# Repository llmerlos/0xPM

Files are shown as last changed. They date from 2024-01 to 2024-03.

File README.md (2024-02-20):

# PICCTRL - 0xPM
## 3x6 + 4 Split Ortholinear Keyboard with on board MCU

## Characteristics:
* [FAK](https://github.com/semickolon/fak) powered
* CH552
* ESD, over-current, short-circuit, reverse polarity protection.
* [Acrylic case](https://github.com/llmerlos/OxPM/PCB/svgs).
* Reversible PCB
* MX and Choc V1 compatibility.

### Choc V1
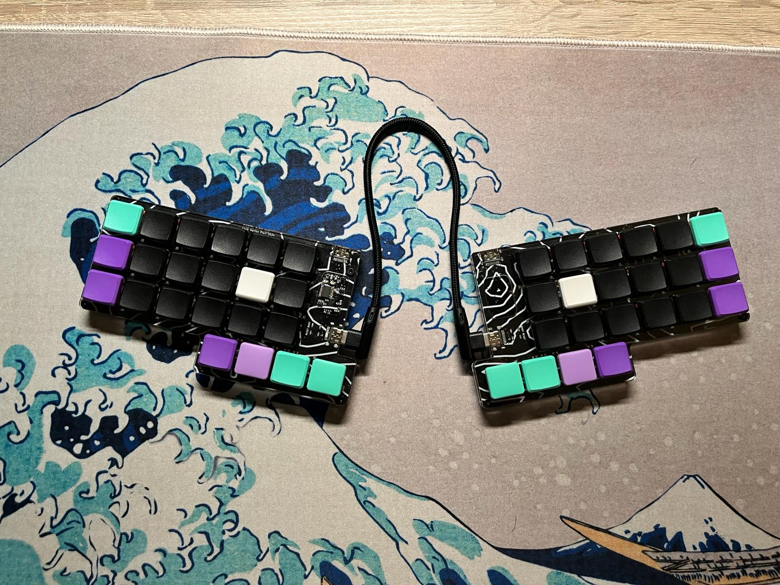
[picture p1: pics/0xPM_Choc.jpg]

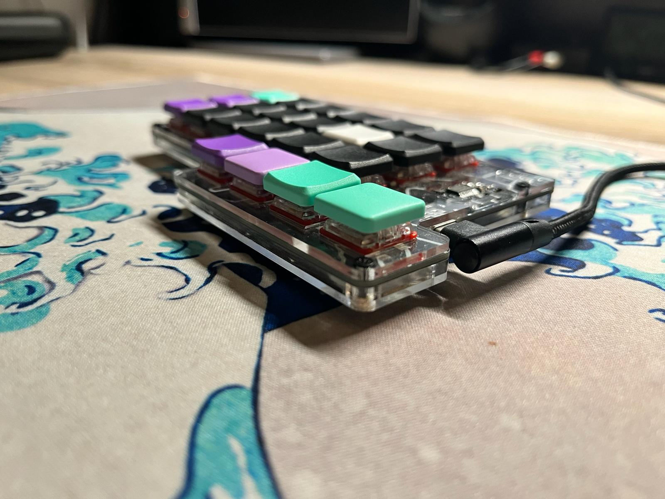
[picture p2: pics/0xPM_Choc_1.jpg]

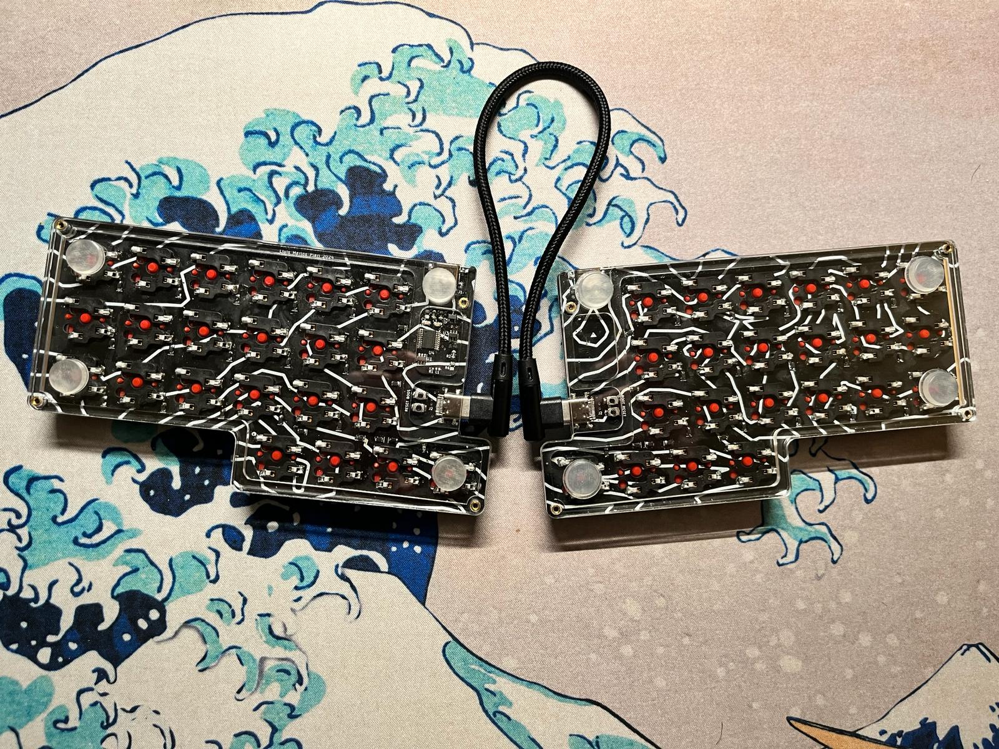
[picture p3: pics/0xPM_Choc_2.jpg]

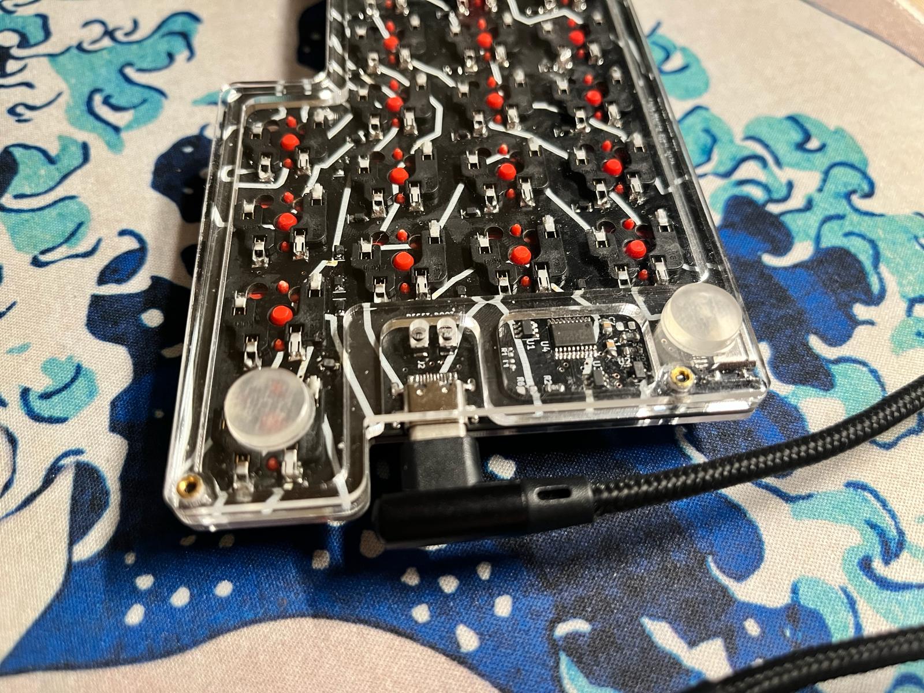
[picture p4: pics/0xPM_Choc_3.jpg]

### MX
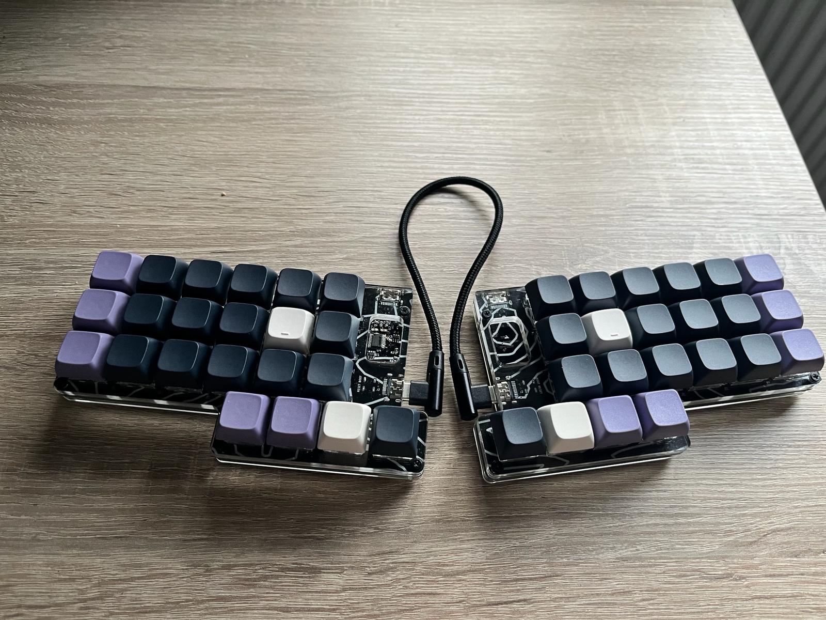
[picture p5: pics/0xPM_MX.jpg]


### Keymap
Nickel files available [here](https://github.com/llmerlos/OxPM/firmware/).

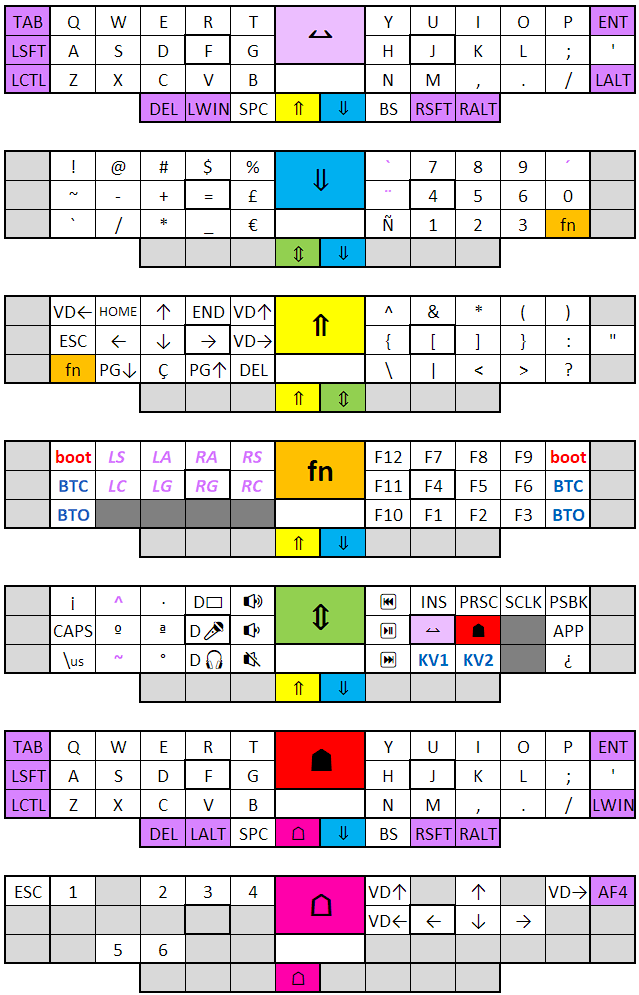
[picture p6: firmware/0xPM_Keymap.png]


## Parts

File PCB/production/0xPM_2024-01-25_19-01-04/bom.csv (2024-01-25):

Designator | Footprint | Quantity | Value | LCSC Part #
B1 | SW_Push_SPST_NO_Alps_SKRK | 1 | BOOT
B2 | SW_Push_SPST_NO_Alps_SKRK | 1 | RESET
C1, C2 | 0805 | 2 | 100nF
D1, D10, D11, D12, D13, D14, D15, D16, D17, D18, D2, D20, D21, D22, D23, D3, D4, D5, D6, D7, D8, D9 | 0805 | 22 | D_Small_Filled
J1, J2 | TYPE-C-31-M-14_Reversible | 2 | USB_C_Receptacle_USB2.0
L1 | 0402 | 1 | PWR/USR LED | C130724
R1 | 0402 | 1 | 1k | C11702
R2, R4, R5 | 0805 | 3 | 5.1k
R3, R6 | 0805 | 2 | 0
SW1, SW10, SW11, SW12, SW13, SW14, SW15, SW16, SW17, SW18, SW2, SW20, SW21, SW22, SW23, SW3, SW4, SW5, SW6, SW7, SW8, SW9 | SW_Hotswap_Kailh_Choc_MX_1.00u | 22 | SW_Push_45deg
U1, U3 | SOT-23-6 | 2 | USBLC6-2SC6
U2 | SOT-23-3 | 1 | CH213K
U4 | TSSOP-20_4.4x6.5mm_P0.65mm | 1 | CH552T

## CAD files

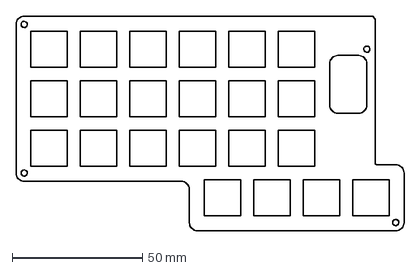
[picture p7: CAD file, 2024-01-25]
PCB/svgs/0xPM-brd-switch.dxf
149.2 x 82.6 mm

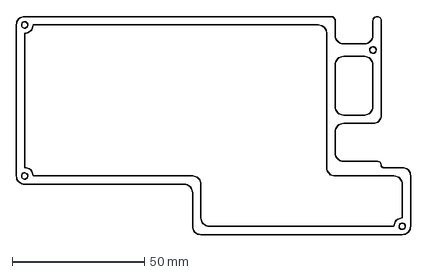
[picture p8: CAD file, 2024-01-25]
PCB/svgs/0xPM-brd-hotswap.dxf
149.2 x 82.6 mm

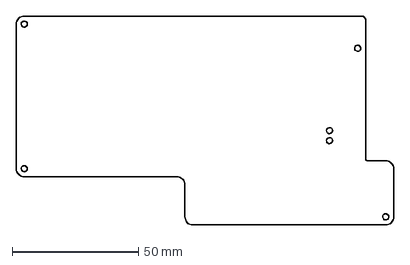
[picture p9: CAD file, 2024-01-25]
PCB/svgs/0xPM-brd-bot.dxf
149.2 x 82.6 mm

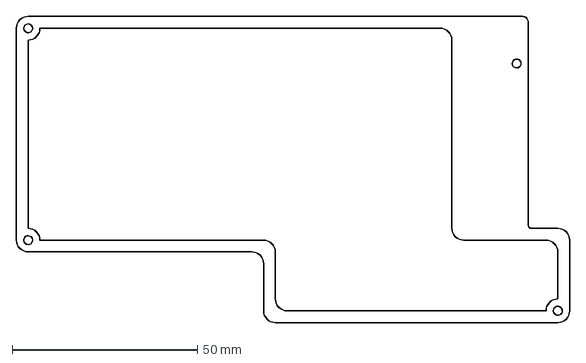
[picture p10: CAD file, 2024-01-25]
PCB/svgs/0xPM-brd-top.dxf
149.2 x 82.6 mm

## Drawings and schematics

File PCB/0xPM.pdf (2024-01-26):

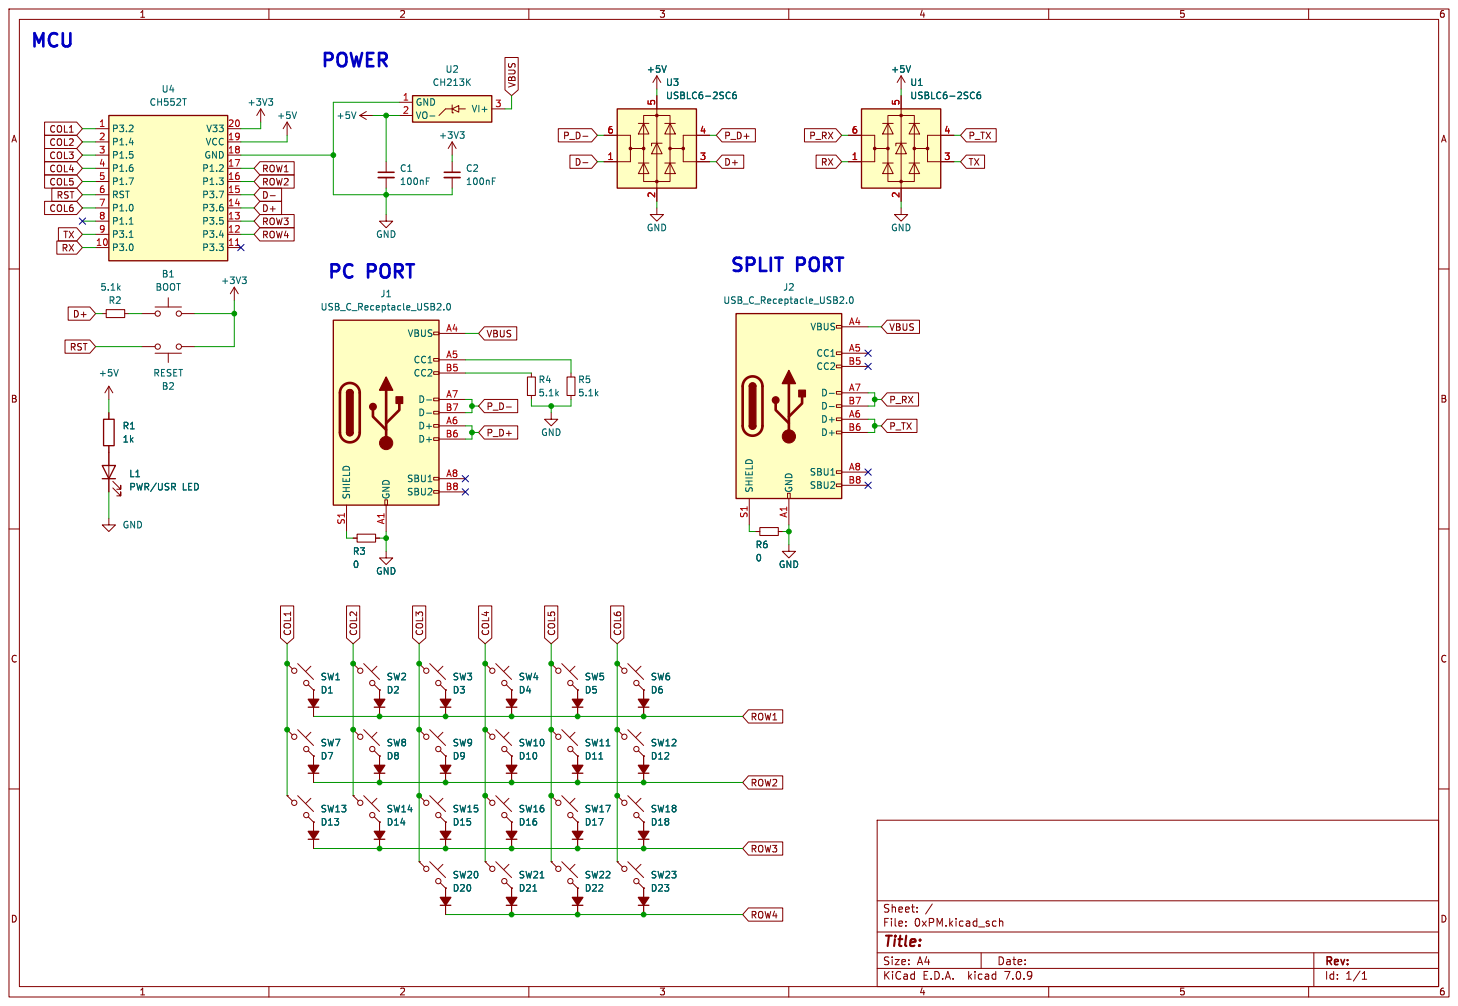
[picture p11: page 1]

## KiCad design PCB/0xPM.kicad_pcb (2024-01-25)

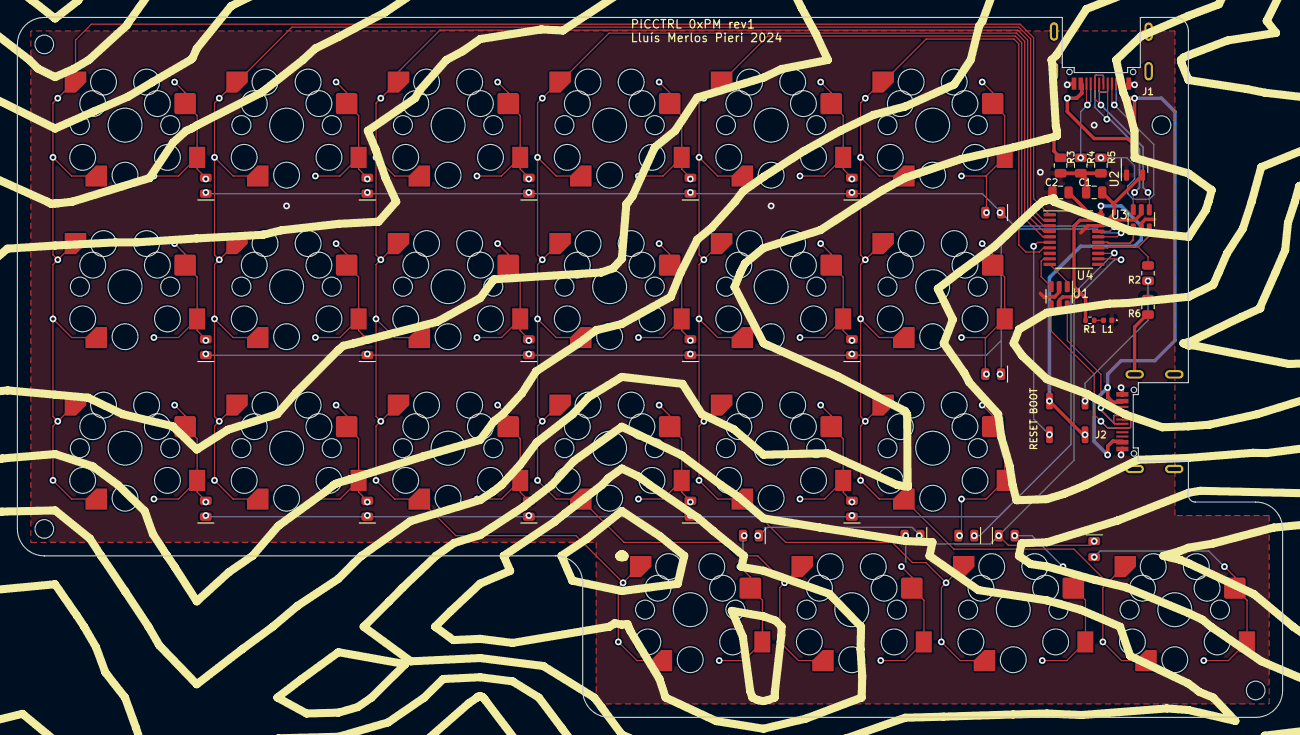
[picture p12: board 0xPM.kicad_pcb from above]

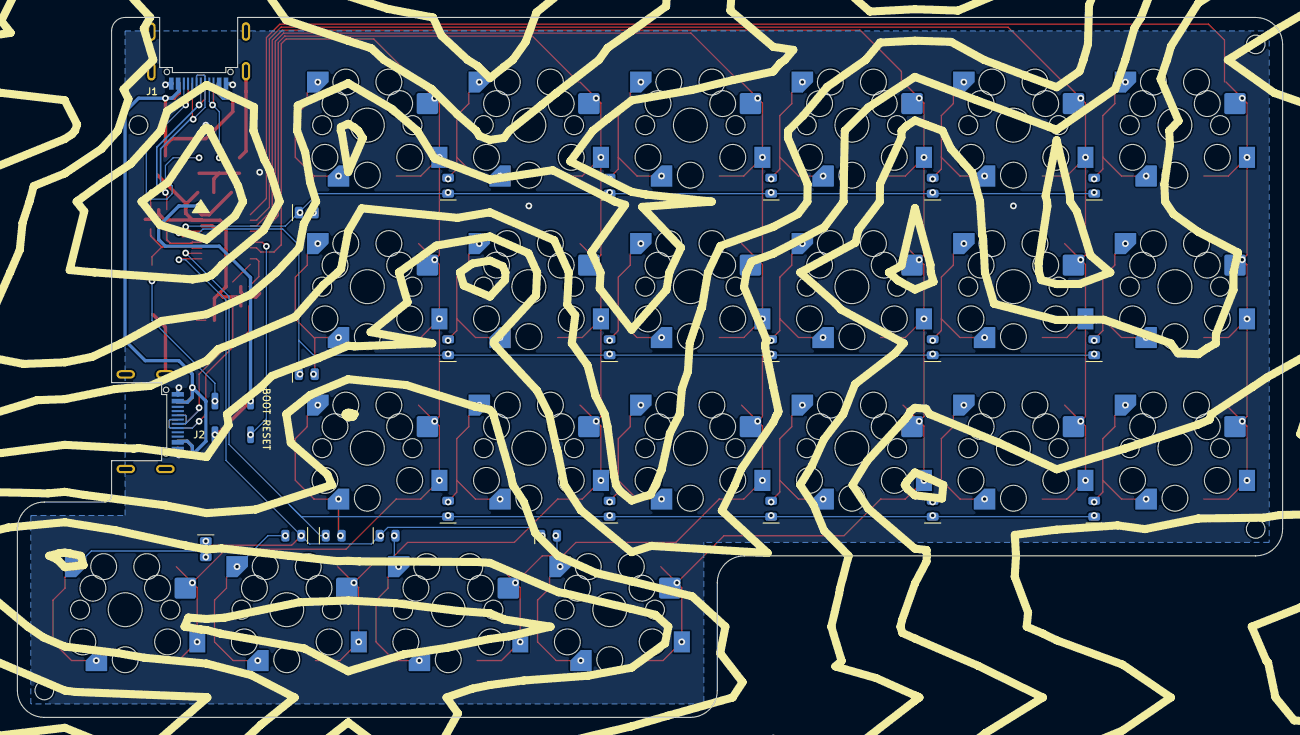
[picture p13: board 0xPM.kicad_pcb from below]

Board: 2 copper layers, 149.2 x 82.5 mm, 61 parts (22 on the bottom side), 51 nets.

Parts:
B1: BOOT; SW_Push_SPST_NO_Alps_SKRK
B2: RESET; SW_Push_SPST_NO_Alps_SKRK
C1, C2: 100nF; C_0805_2012Metric
D1, D2, D3, D4, D5, D6, D7, D8, D9, D10, D11, D12, D13, D14, D15, D16, D17, D18, D20, D21, D22, D23: D_Small_Filled; D_0805_2012Metric_Reversible
J1, J2: USB_C_Receptacle_USB2.0; TYPE-C-31-M-14_Reversible
L1: PWR/USR LED; LED_0402_1005Metric
R1: 1k; R_0402_1005Metric
R2, R4, R5: 5.1k; R_0805_2012Metric
R3, R6: 0; R_0805_2012Metric
SW1, SW2, SW3, SW4, SW5, SW6, SW7, SW8, SW9, SW10, SW11, SW12, SW13, SW14, SW15, SW16, SW17, SW18, SW20, SW21, SW22, SW23: SW_Push_45deg; SW_Hotswap_Kailh_Choc_MX_1.00u
U1, U3: USBLC6-2SC6; SOT-23-6
U2: CH213K; SOT-23-3
U4: CH552T; TSSOP-20_4.4x6.5mm_P0.65mm

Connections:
+3V3: B1.2, B2.1, C2.1, U4.20 (V33)
+5V: C1.1, R1.1, U1.5 (VBUS), U2.2 (VO-), U3.5 (VBUS), U4.19 (VCC)
COL1: SW1.1, SW7.1, SW13.1, U4.1 (P3.2)
COL2: SW2.1, SW8.1, SW14.1, U4.2 (P1.4)
COL3: SW3.1, SW9.1, SW15.1, SW20.1, U4.3 (P1.5)
COL4: SW4.1, SW10.1, SW16.1, SW21.1, U4.4 (P1.6)
COL5: SW5.1, SW11.1, SW17.1, SW22.1, U4.5 (P1.7)
COL6: SW6.1, SW12.1, SW18.1, SW23.1, U4.7 (P1.0)
D+: R2.1, U3.3 (I/O2), U4.14 (P3.6)
D-: U3.1 (I/O1), U4.15 (P3.7)
GND: C1.2, C2.2, J1.A1 (GND), J1.A12 (GND), J1.B1 (GND), J1.B12 (GND), J2.A1 (GND), J2.A12 (GND), J2.B1 (GND), J2.B12 (GND), L1.1 (K), R3.2, R4.2, R5.1, R6.2, U1.2 (GND), U2.1 (GND), U3.2 (GND), U4.18 (GND)
unnamed: B1.1, R2.2
unnamed: D1.2 (A), SW1.2
unnamed: D2.2 (A), SW2.2
unnamed: D3.2 (A), SW3.2
unnamed: D4.2 (A), SW4.2
unnamed: D5.2 (A), SW5.2
unnamed: D6.2 (A), SW6.2
unnamed: D7.2 (A), SW7.2
unnamed: D8.2 (A), SW8.2
unnamed: D9.2 (A), SW9.2
unnamed: D10.2 (A), SW10.2
unnamed: D11.2 (A), SW11.2
unnamed: D12.2 (A), SW12.2
unnamed: D13.2 (A), SW13.2
unnamed: D14.2 (A), SW14.2
unnamed: D15.2 (A), SW15.2
unnamed: D16.2 (A), SW16.2
unnamed: D17.2 (A), SW17.2
unnamed: D18.2 (A), SW18.2
unnamed: D20.2 (A), SW20.2
unnamed: D21.2 (A), SW21.2
unnamed: D22.2 (A), SW22.2
unnamed: D23.2 (A), SW23.2
unnamed: J1.A5 (CC1), R5.2
unnamed: J1.B5 (CC2), R4.1
unnamed: J1.S1 (SHIELD), R3.1
unnamed: J2.S1 (SHIELD), R6.1
unnamed: L1.2 (A), R1.2
P_D+: J1.A6 (D+), J1.B6 (D+), U3.4 (I/O2)
P_D-: J1.A7 (D-), J1.B7 (D-), U3.6 (I/O1)
P_RX: J2.A7 (D-), J2.B7 (D-), U1.6 (I/O1)
P_TX: J2.A6 (D+), J2.B6 (D+), U1.4 (I/O2)
ROW1: D1.1 (K), D2.1 (K), D3.1 (K), D4.1 (K), D5.1 (K), D6.1 (K), U4.17 (P1.2)
ROW2: D7.1 (K), D8.1 (K), D9.1 (K), D10.1 (K), D11.1 (K), D12.1 (K), U4.16 (P1.3)
ROW3: D13.1 (K), D14.1 (K), D15.1 (K), D16.1 (K), D17.1 (K), D18.1 (K), U4.13 (P3.5)
ROW4: D20.1 (K), D21.1 (K), D22.1 (K), D23.1 (K), U4.12 (P3.4)
RST: B2.2, U4.6 (RST)
RX: U1.1 (I/O1), U4.10 (P3.0)
TX: U1.3 (I/O2), U4.9 (P3.1)
VBUS: J1.A4 (VBUS), J1.A9 (VBUS), J1.B4 (VBUS), J1.B9 (VBUS), J2.A4 (VBUS), J2.A9 (VBUS), J2.B4 (VBUS), J2.B9 (VBUS), U2.3 (VI+)
